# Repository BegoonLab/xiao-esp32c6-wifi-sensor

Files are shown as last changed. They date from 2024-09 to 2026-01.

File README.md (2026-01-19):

# Smart IoT Sensor built with XIAO ESP32C6

**Wi-Fi, MQTT, BME280/BME680/SGP41 Integration & Power Management**

## Table of Contents

- [Introduction](#introduction)
- [Features](#features)
- [Usage](#usage)
- [Schematics](#schematics)
- [Configuration](#configuration)
- [Enclosure](#enclosure)
- [Integration with Home Assistant](#integration-with-home-assistant)
- [Getting Started](#getting-started)
- [Hardware](#hardware)
- [Software](#software)
- [ZigBee](#zigbee)
- [Contributing](#contributing)
- [License](#license)
- [TODO](#todo)

## Introduction

The Smart IoT Sensor is a power-efficient device built using the [XIAO ESP32C6](https://wiki.seeedstudio.com/xiao_esp32c6_getting_started/) tiny board. It integrates Wi-Fi connectivity, MQTT messaging, environmental sensing with BME280/BME680 sensors, and robust power management, making it an ideal solution for smart home and IoT applications.

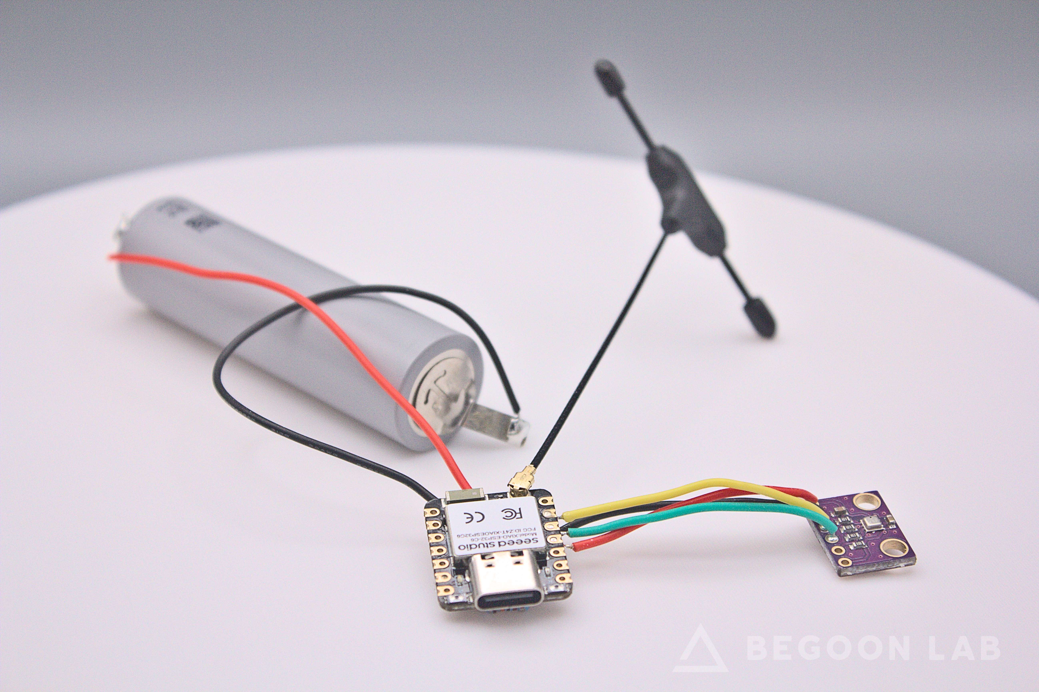
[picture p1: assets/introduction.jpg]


## Features

- **Wi-Fi Connectivity**: Seamless connection to your home or office network.
- **MQTT Integration**: Publishes sensor data to an MQTT broker in JSON format.
- **Environmental Sensing**: Supports [Bosch BME280](https://www.bosch-sensortec.com/products/environmental-sensors/humidity-sensors-bme280/) and [BME680](https://www.bosch-sensortec.com/products/environmental-sensors/gas-sensors/bme680/) sensors for temperature, humidity, and pressure measurements. Supports [Sensirion SGP41](https://sensirion.com/products/catalog/SGP41) VOC and NOx sensor.
- **Power Management**: Efficiently manages power using LiPo batteries with built-in charge management.
- **Deep Sleep Mode**: Extends battery life by enabling deep sleep between data transmissions.
- **ZigBee Connectivity**: Seamless integration with ZigBee networks. Supports standard ZigBee clusters, easily pair your sensor with ZigBee coordinators like Home Assistant.
- **Optional Features**:
  - Battery voltage monitoring
  - Connection duration tracking
  - Future support for Wi-Fi 6 and Bluetooth provisioning (TODO)

## Usage

The Smart IoT Sensor can be easily integrated with [Home Assistant](https://www.home-assistant.io/) for real-time monitoring and automation.

### MQTT Data Structure

The sensor publishes data to an MQTT broker in the following JSON format:

```json
{
  "ID": "7i29r9k9ltaxmbev",
  "RSSI": -54,
  "battery_voltage": 4.13,
  "temperature": "24.28",
  "humidity": "29.32",
  "pressure": "999.54",
  "connection_duration_ms": 1672
}
```

- **ID**: Unique identifier of the sensor
- **RSSI**: Wi-Fi signal strength in dBm
- **battery_voltage**: Current battery voltage
- **temperature**: Temperature reading from the BME sensor
- **humidity**: Humidity reading from the BME sensor
- **pressure**: Pressure reading from the BME sensor
- **connection_duration_ms**: Time taken to establish the MQTT connection

## Schematics

### Battery Connection

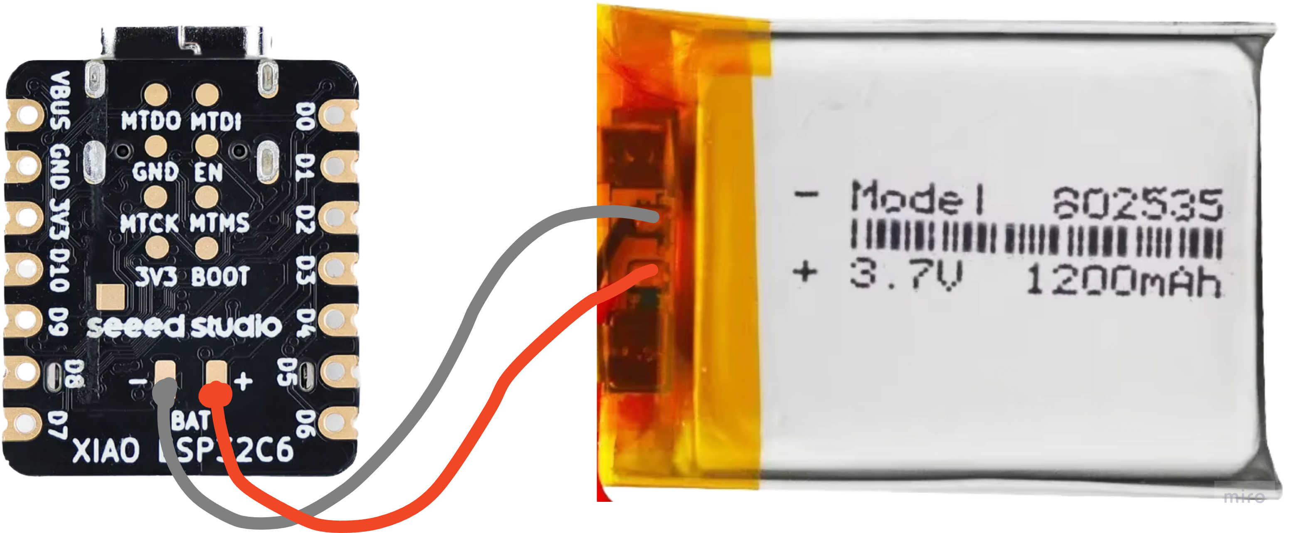
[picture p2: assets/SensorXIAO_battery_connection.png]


_A battery connection schematic._

### Voltage Divider

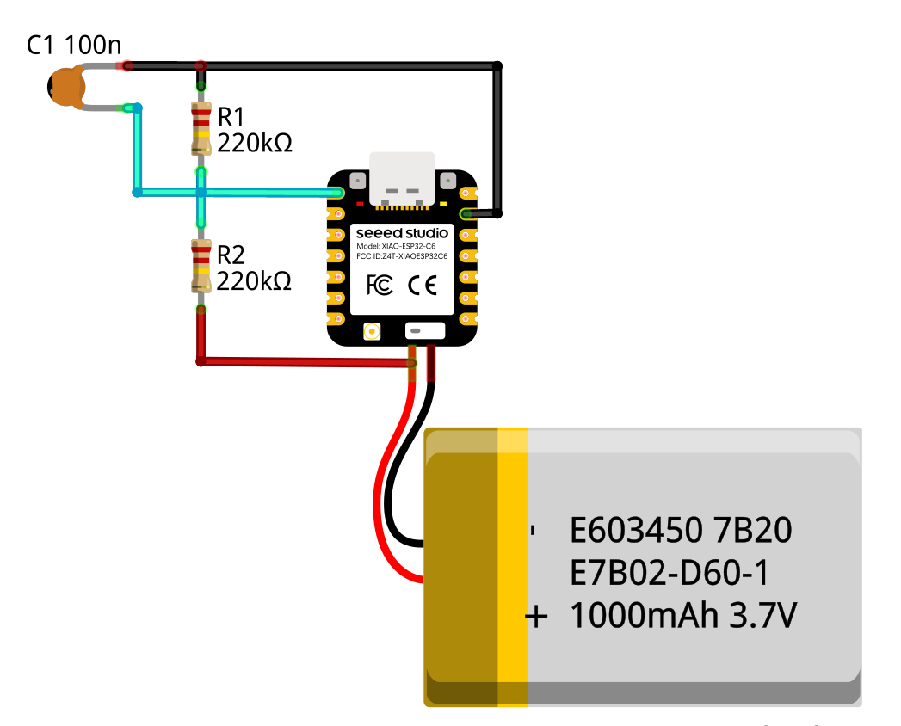
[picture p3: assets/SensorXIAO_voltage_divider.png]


_Voltage divider schematic (if battery voltage monitoring is required)._

**Note:** This solution continuously consumes some current from the battery but is functional for voltage monitoring.

### BME280/BME680 Connection

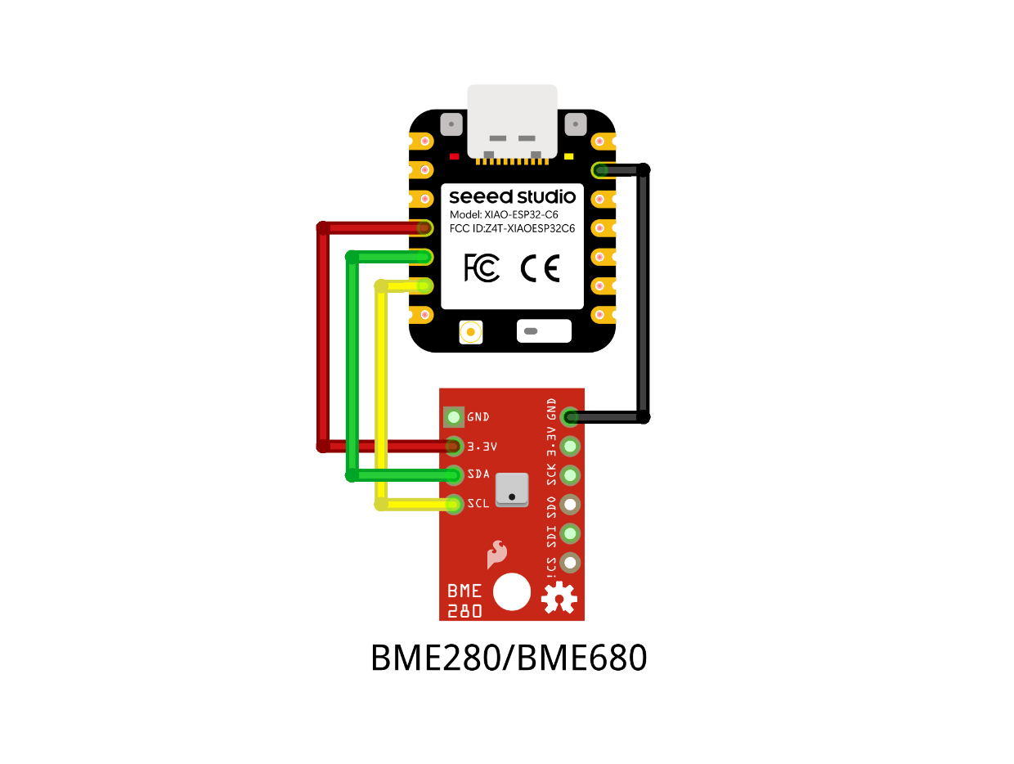
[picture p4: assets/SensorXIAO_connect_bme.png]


### SGP41 Connection

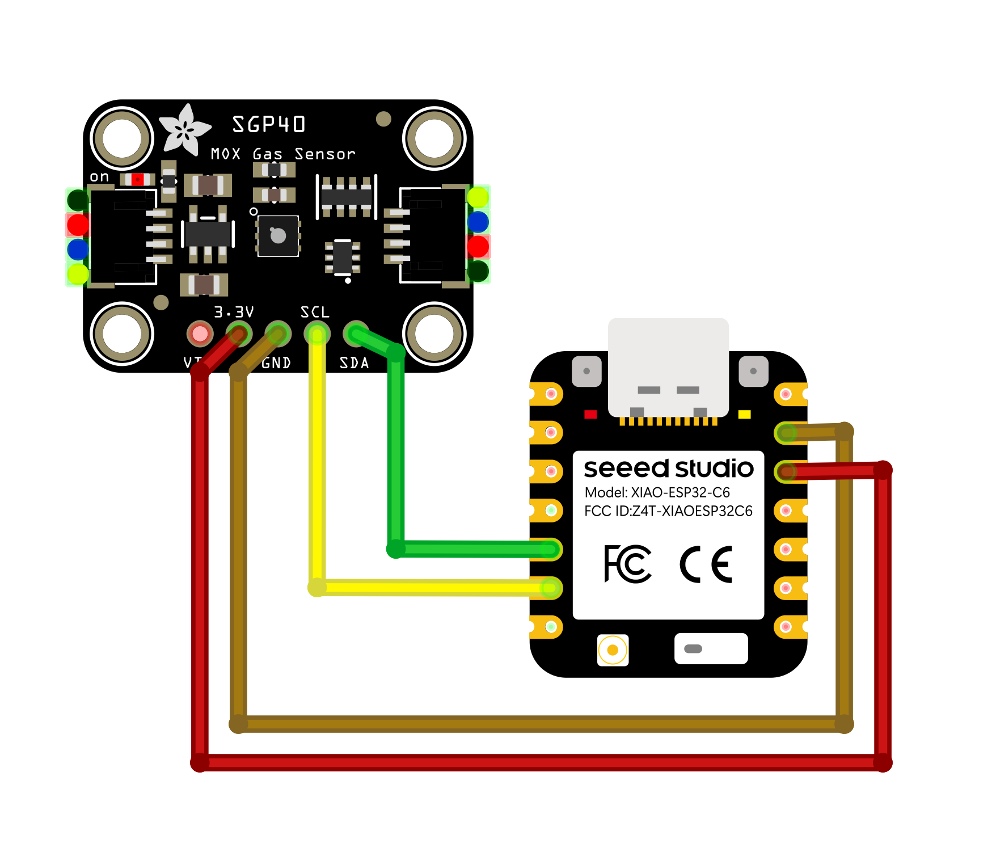
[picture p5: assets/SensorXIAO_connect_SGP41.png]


## Configuration

This build was developed and tested with [ESP-IDF v5.5.2](https://github.com/espressif/esp-idf/releases/tag/v5.5.2)
Follow [this instruction](https://docs.espressif.com/projects/esp-idf/en/v5.5.2/esp32/get-started/index.html#manual-installation) to install it. It is required.

Configure the sensor using the following steps:

```
idf.py menuconfig
```

Then go to `XIAO Sensor Configuration`

1. **Wi-Fi Configuration**: Set up your Wi-Fi credentials to enable network connectivity.
2. **MQTT Configuration**: Connect the sensor to your MQTT server by providing the necessary broker details.
3. **Battery Check (Optional)**: Enable battery voltage monitoring if power management insights are needed.
4. **BME Sensor Configuration (Optional)**: Choose between BME280, BME680 and SGP41 sensors based on your requirements.
5. **Power Management Configuration**: Set up wakeup duration, which is the duration in seconds that the device will remain in deep sleep before waking up.

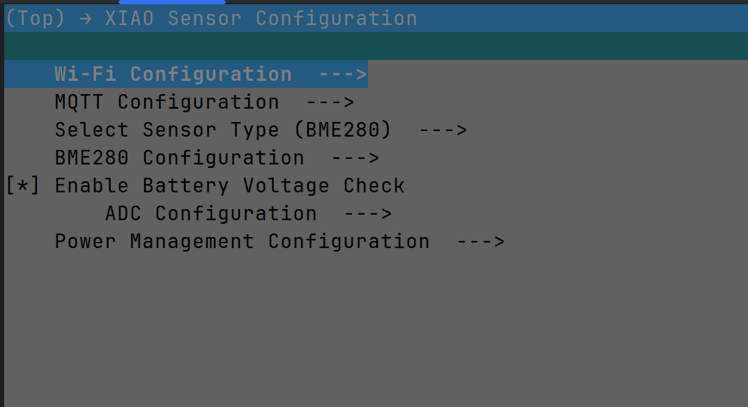
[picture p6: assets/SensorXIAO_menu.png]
6. 

## Enclosure

The sensor is housed in a customizable 3D-printed enclosure. [STL files](3d/enclosure/stl) are available for download and 3D printing.
To customize a model use a [FreeCAD project](3d/enclosure/XIAO_ESP32C6_Enclosure.FCStd).
A 3D preview is available [here](https://begoonlab.tech/cad_design/instructables.com/XIAO_ESP32C6_Enclosure.html).

When printing, it is recommended to orient the parts on the hotbed as shown in the picture:

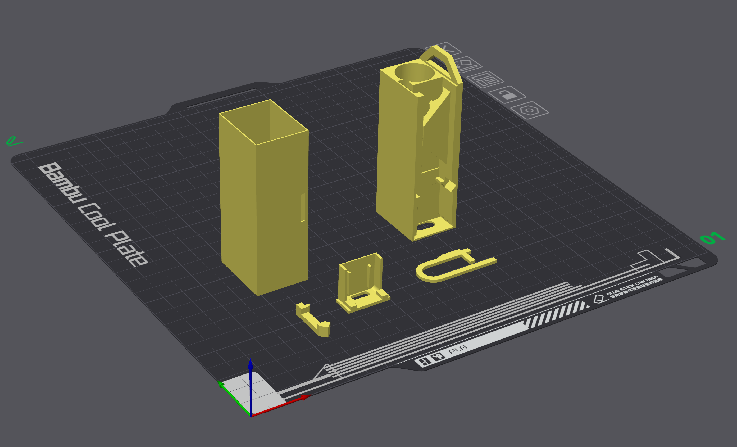
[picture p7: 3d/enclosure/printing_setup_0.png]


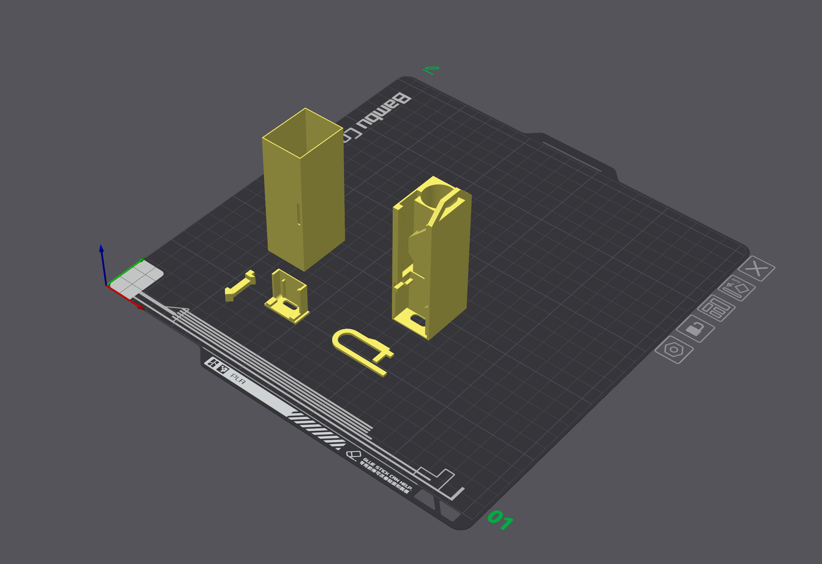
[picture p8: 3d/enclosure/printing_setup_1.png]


Enclosure assembly steps:

1. Insert XIAO board into [SoC_holder](3d/enclosure/stl/soc_holder.stl) :

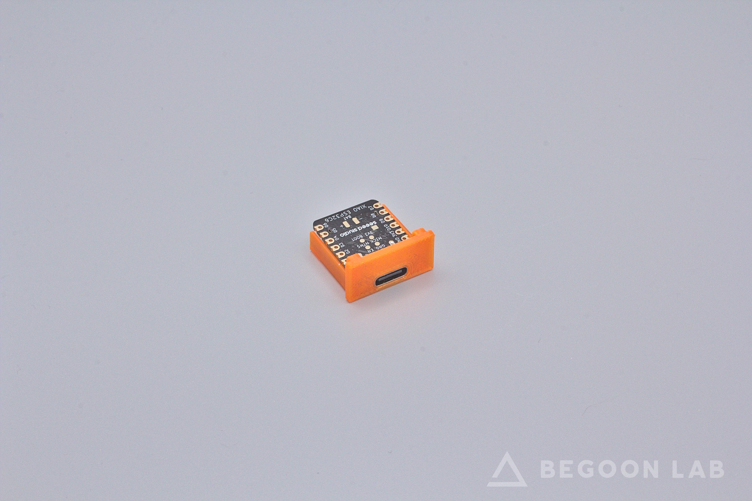
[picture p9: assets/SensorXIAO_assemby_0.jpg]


2. Insert holder into the [core part](3d/enclosure/stl/core.stl) :

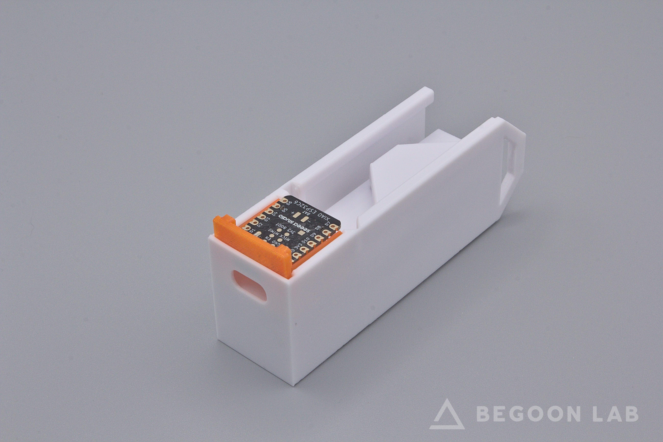
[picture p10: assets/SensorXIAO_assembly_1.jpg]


Pull down until it can't go any farther

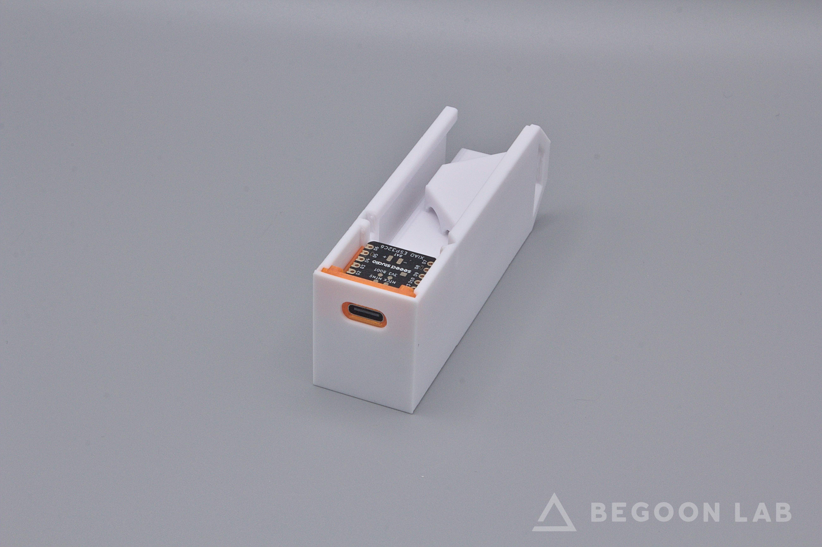
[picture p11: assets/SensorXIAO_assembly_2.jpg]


3. Insert [SoC bracket](3d/enclosure/stl/soc_bracket.stl) :

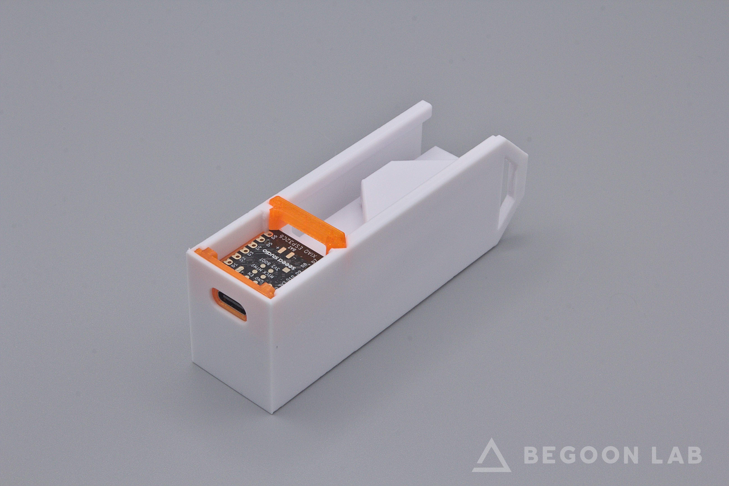
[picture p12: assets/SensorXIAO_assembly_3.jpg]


4. Insert BME sensor

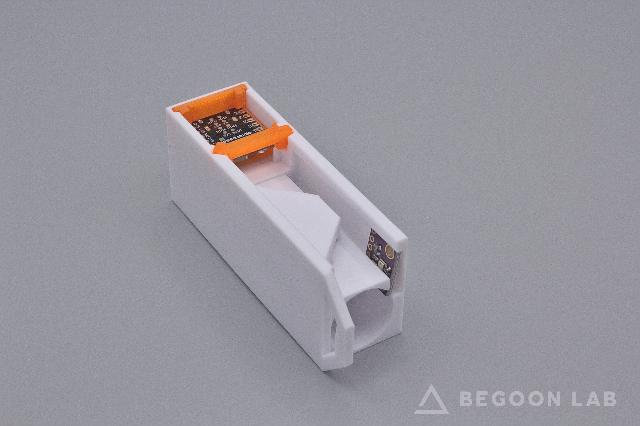
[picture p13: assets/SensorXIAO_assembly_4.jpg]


5. Attach an antenna. Put the coaxial wire into the channels in the core part. Use a couple of drops of glue or double-sided tape to secure the antenna in its place.

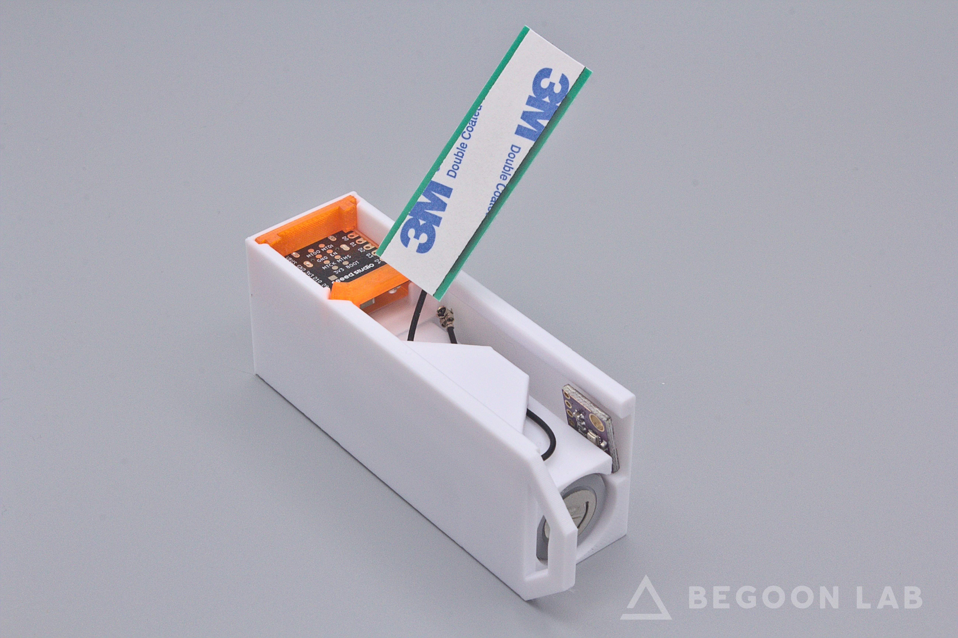
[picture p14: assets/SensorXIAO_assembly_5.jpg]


6. Now solder up everything together according to [schematics](#schematics). And repeat an assembly steps if everything fits nicely.

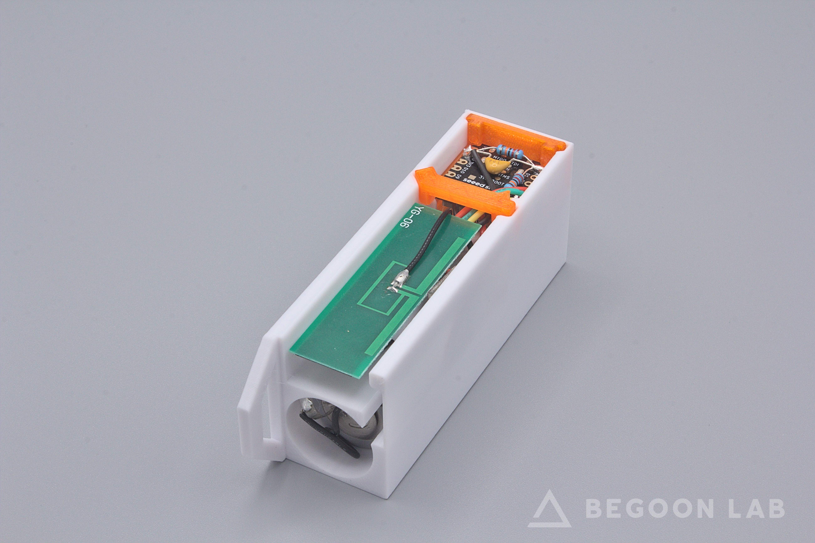
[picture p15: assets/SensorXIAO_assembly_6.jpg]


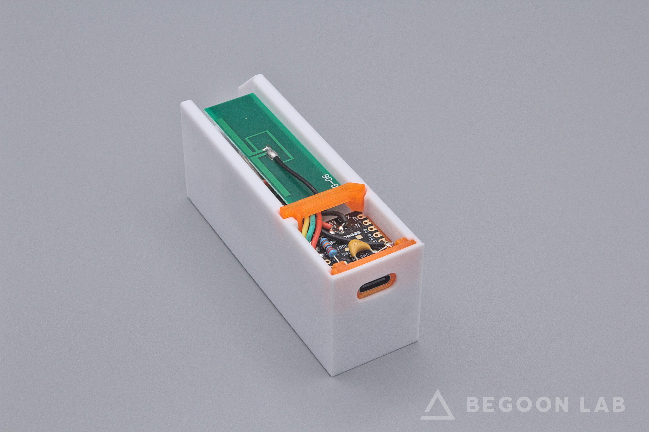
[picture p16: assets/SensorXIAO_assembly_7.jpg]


7. Insert [lock](3d/enclosure/stl/lock.stl) into the [core part](3d/enclosure/stl/core.stl) as shown:

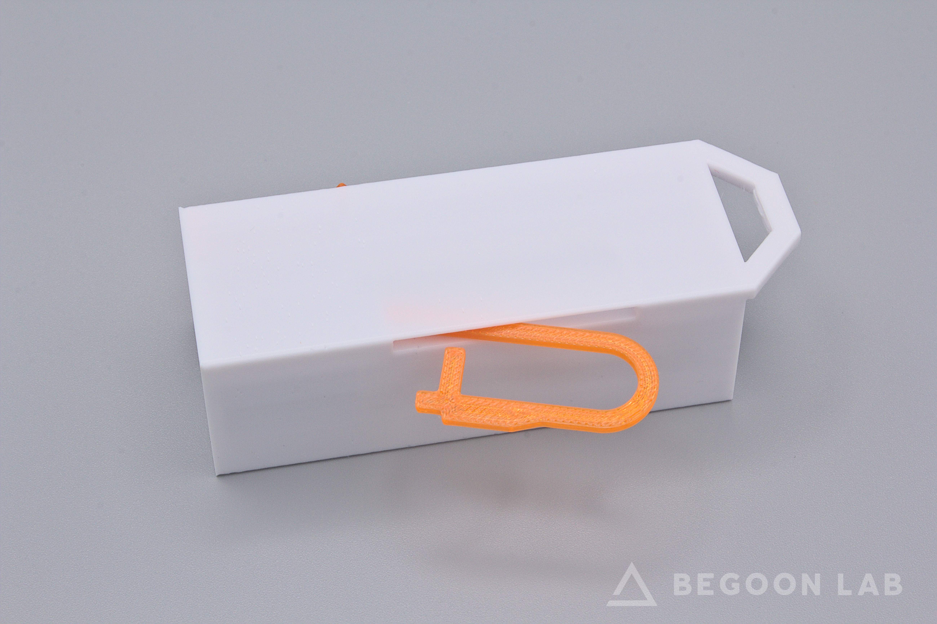
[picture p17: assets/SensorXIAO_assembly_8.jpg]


8. Finally, pull [the wrapper](3d/enclosure/stl/wrapper.stl) onto the [core part](3d/enclosure/stl/core.stl). Ensure that the [lock](3d/enclosure/stl/lock.stl) is securing the wrapper.

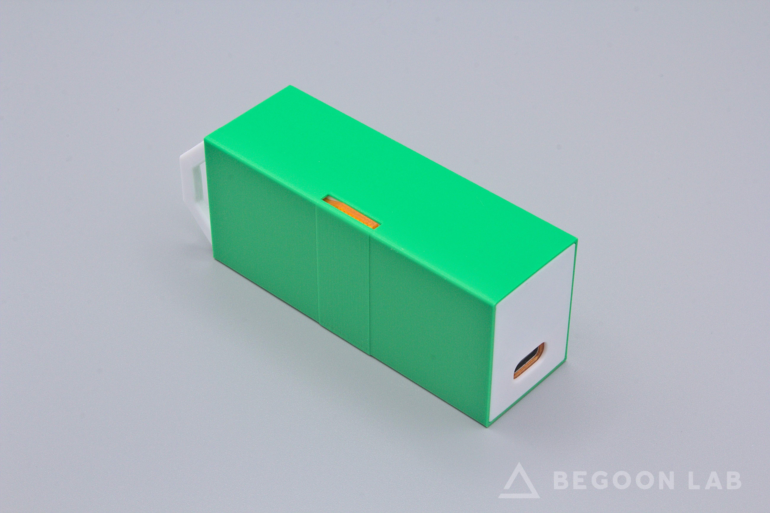
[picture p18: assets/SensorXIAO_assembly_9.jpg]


## Integration with Home Assistant

Integrate the Smart IoT Sensor with Home Assistant by following these steps:

1. **Set Up MQTT Server**: If you don't have an MQTT server, refer to the [Home Assistant MQTT Integration](https://www.home-assistant.io/integrations/mqtt/) guide.
2. **Configure `configuration.yaml`**: Add the following configuration to your `configuration.yaml` file to define the sensor entities.

```yaml
---
mqtt:
  sensor:
    - name: "Sensor RSSI 7i29r9k9ltaxmbev"
      device_class: signal_strength
      state_topic: "xiao/sensor/7i29r9k9ltaxmbev/data"
      unit_of_measurement: "dBm"
      value_template: "{{ value_json.RSSI }}"

    - name: "Sensor Temperature 7i29r9k9ltaxmbev"
      device_class: temperature
      state_topic: "xiao/sensor/7i29r9k9ltaxmbev/data"
      unit_of_measurement: "°C"
      value_template: "{{ value_json.temperature }}"

    - name: "Sensor Humidity 7i29r9k9ltaxmbev"
      device_class: humidity
      state_topic: "xiao/sensor/7i29r9k9ltaxmbev/data"
      unit_of_measurement: "%"
      value_template: "{{ value_json.humidity }}"

    - name: "Sensor Pressure 7i29r9k9ltaxmbev"
      device_class: pressure
      state_topic: "xiao/sensor/7i29r9k9ltaxmbev/data"
      unit_of_measurement: "hPa"
      value_template: "{{ value_json.pressure }}"

    - name: "Sensor Battery Voltage 7i29r9k9ltaxmbev"
      device_class: voltage
      state_topic: "xiao/sensor/7i29r9k9ltaxmbev/data"
      unit_of_measurement: "V"
      value_template: "{{ value_json.battery_voltage }}"

    - name: "Sensor Connection Duration 7i29r9k9ltaxmbev"
      device_class: duration
      state_topic: "xiao/sensor/7i29r9k9ltaxmbev/data"
      unit_of_measurement: "ms"
      value_template: "{{ value_json.connection_duration_ms }}"
```

3. **Restart Home Assistant**: After updating the configuration, restart Home Assistant to apply the changes.
4. **Configure Entity Card**: Here is an example configuration for the entity card:

```yaml
---
type: entities
entities:
  - entity: sensor.sensor_temperature_7i29r9k9ltaxmbev
    icon: mdi:thermometer-low
    secondary_info: last-changed
    name: Temperature
  - entity: sensor.sensor_humidity_7i29r9k9ltaxmbev
    name: Humidity
  - entity: sensor.sensor_pressure_7i29r9k9ltaxmbev
    name: Pressure
  - entity: sensor.sensor_rssi_7i29r9k9ltaxmbev
    icon: mdi:wifi-strength-3
    secondary_info: none
    name: RSSI
  - entity: sensor.sensor_battery_voltage_7i29r9k9ltaxmbev
    icon: mdi:battery-80
    secondary_info: none
    name: Battery
  - entity: sensor.sensor_connection_duration_7i29r9k9ltaxmbev
    name: Connection Duration
title: Sensor 7i29r9k9ltaxmbev
```

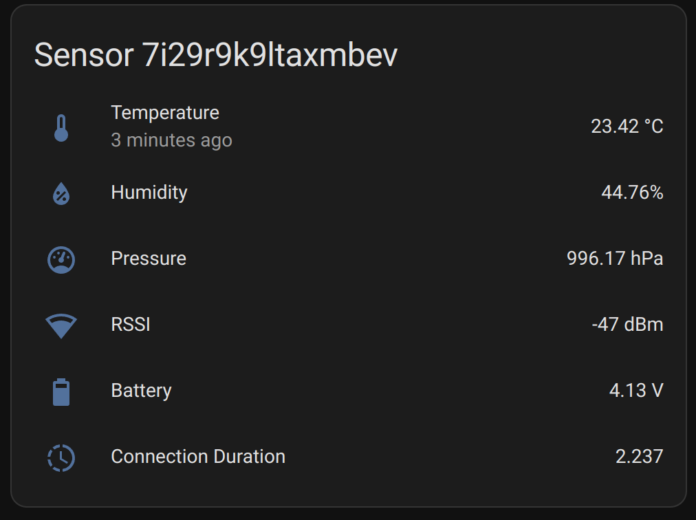
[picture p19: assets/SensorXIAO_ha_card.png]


## Getting Started

Follow these steps to set up your Smart IoT Sensor:

1. **Clone the Repository**

   ```bash
   git clone https://github.com/BegoonLab/xiao-esp32c6-wifi-sensor
   cd xiao-esp32c6-wifi-sensor
   git submodule update --init --recursive
   ```

2. **Install Dependencies**

   Ensure you have the necessary tools and libraries installed. Refer to the [Software](#software) section for more details.

3. **Configure the Sensor**

   Edit the configuration files to set your Wi-Fi and MQTT credentials.

4. **Build and Flash**

   Compile the firmware and flash it to your XIAO ESP32C6 board.

5. **Assemble the Hardware**

   Connect the BME sensor and battery as per the schematics. 3D print the enclosure and assemble the components.

6. **Deploy and Monitor**

   Power on the sensor and monitor the data through your MQTT broker and Home Assistant.

## Hardware

### Components Required

- **XIAO ESP32C6**: The main microcontroller unit.
- **Bosch BME280 or BME680 Sensor**: For measuring temperature, humidity, and pressure.
- **LiPo Battery**: Any standard LiPo battery compatible with XIAO's charge management.
- **Voltage Divider Components**: If battery voltage monitoring is required.
- **Additional Components**:
  - Connectors and cables
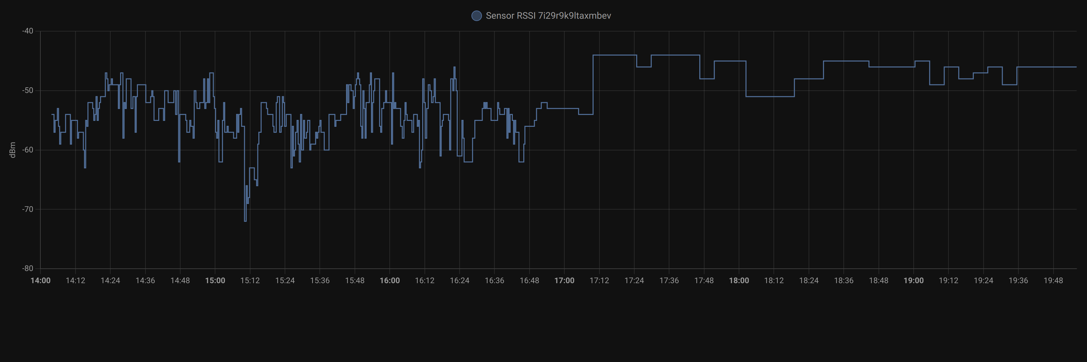
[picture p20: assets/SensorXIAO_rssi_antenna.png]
  - External antenna (optional, but highly recommended for weak Wi-Fi signals). This is RSSI without and then with external antenna: 
    - These antennas tested and worked quite well with this build:
    - PCB Antenna 5dBi and U.FL connector
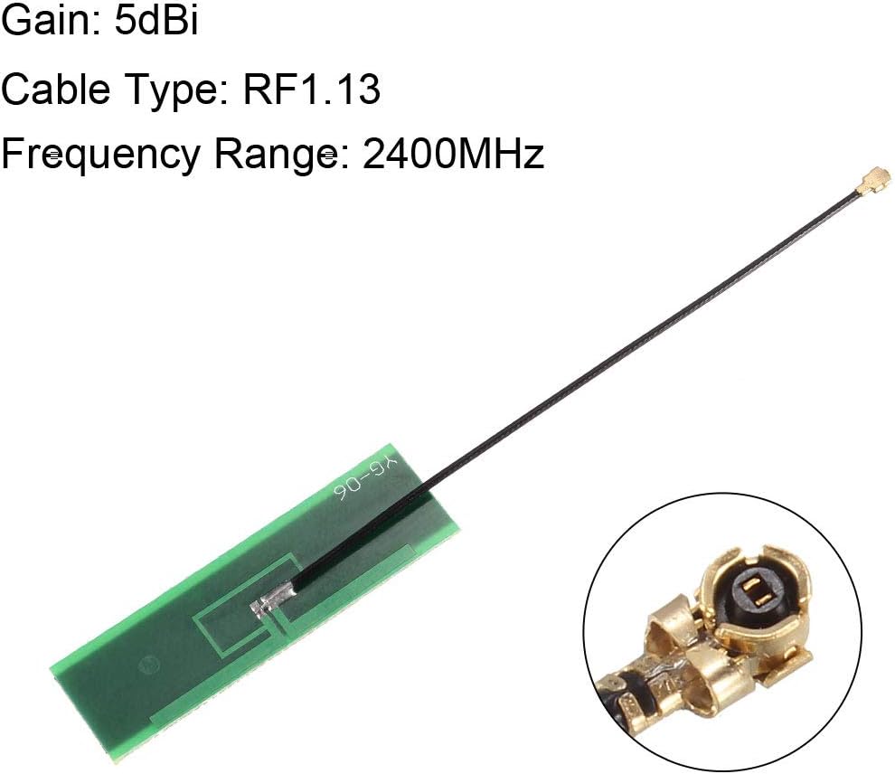
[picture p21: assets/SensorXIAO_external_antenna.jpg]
    - 
    - RadioMaster FPV Drone antenna
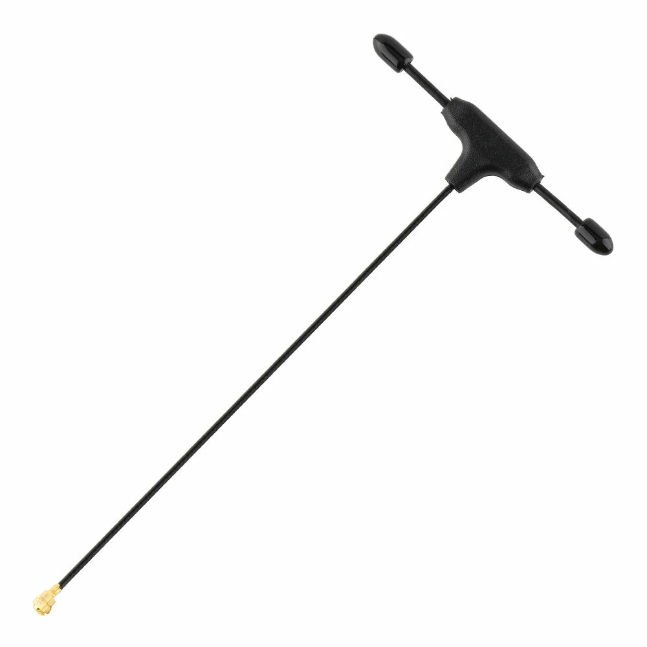
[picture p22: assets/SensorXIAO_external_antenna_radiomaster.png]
    - 

### Assembly Instructions

1. **Mount the Sensor**: Connect the BME280/BME680 to the XIAO ESP32C6.
2. **Connect the Battery**: Ensure the battery is properly connected to the charge management circuitry.
3. **Set Up Voltage Divider**: If monitoring battery voltage, assemble the voltage divider as per the schematic.
4. **Enclose the Assembly**: Use the 3D-printed enclosure to house all components securely.

## Software

### Dependencies

- **ESP-IDF**: [Official development framework](https://docs.espressif.com/projects/esp-idf/en/v5.5.2/esp32/get-started/index.html#software) for Espressif chips.

### Building the Firmware

1. **Install ESP-IDF**

   Follow the [ESP-IDF Getting Started Guide](https://docs.espressif.com/projects/esp-idf/en/v5.5.2/esp32/get-started/index.html) to set up the development environment.

2. **Configure the Project**

   ```bash
   idf.py menuconfig
   ```

   - Set Wi-Fi credentials
   - Configure MQTT broker details
   - Enable or disable optional features

3. **Build and Flash**

   ```bash
   idf.py build
   idf.py -p <TARGET_PORT> flash
   ```

When a sensor misbehaves, it's helpful to output logs to diagnose the issue. By default, logging is disabled. To enable it, follow these steps:

1. Open the configuration menu:
   ```bash
   idf.py menuconfig
   ```
2. Navigate to:
   `Component config` → `Log output` → `Default log verbosity`.
3. Set the verbosity level to `Info`.
4. Save the changes, and then execute the following command to build, flash, and monitor:
   ```bash
   idf.py -p <TARGET_PORT> build flash monitor
   ```

## ZigBee

ZigBee can be activated in the menu:

```bash
idf.py menuconfig
```

Navigate to `XIAO Sensor Configuration` → `Select Sensor Connection Type` → `ZigBee`.

Next, go to `Component config` → `Zigbee` → `Zigbee Enable` and set it to ON. Then, go to `XIAO Sensor Configuration` → `ZigBee Configuration` and set a `Sensor ID`.

Build and flash the firmware. After that, the sensor will be ready and will begin commissioning.

To add the sensor to Home Assistant: go to `Settings` → `Devices & Services` → `Devices` → `Add Device` → `Add Zigbee device`. Once completed, your sensor will appear on the Devices page:

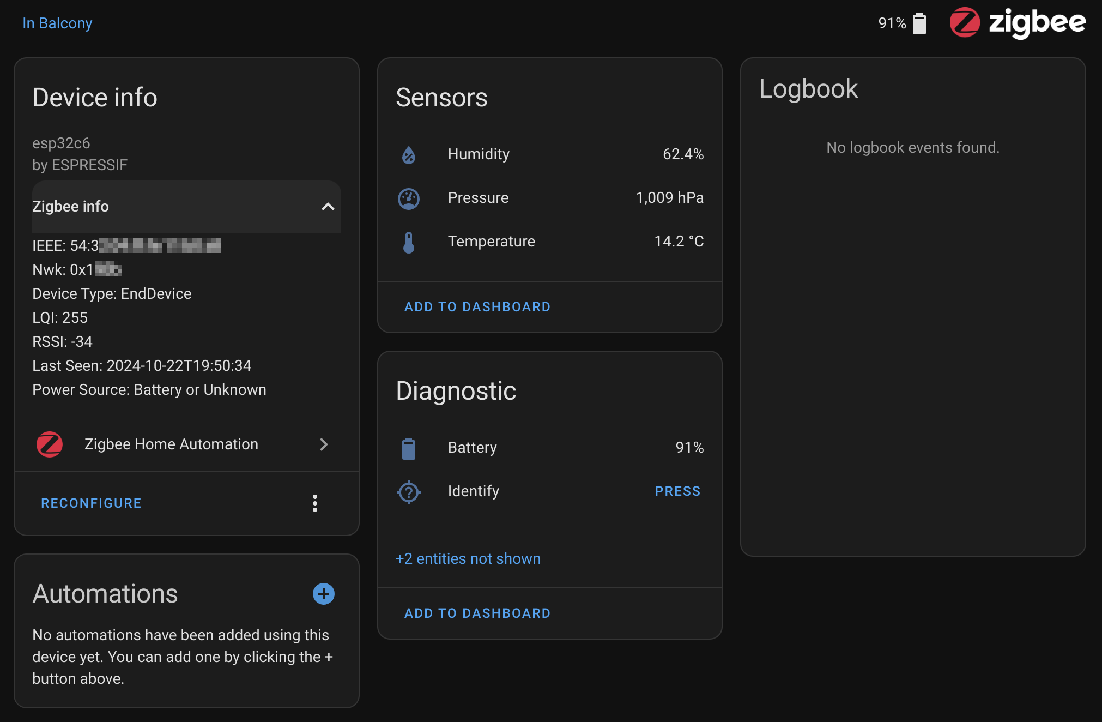
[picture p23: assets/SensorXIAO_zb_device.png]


_Note_: The SGP41 sensor is not currently supported because the ZigBee protocol does not include VOC and NOx clusters in its specification.

## Contributing

Contributions are welcome! Please follow these steps:

1. **Fork the Repository**
2. **Create a Feature Branch**

   ```bash
   git checkout -b feature/YourFeature
   ```

3. **Commit Your Changes**
4. **Push to the Branch**

   ```bash
   git push origin feature/YourFeature
   ```

5. **Open a Pull Request**

## License

This project is licensed under the [MIT License](LICENSE). All rights reserved.

## TODO

- **Wi-Fi 6 Support**: Enhance connectivity options with Wi-Fi 6.
- **Bluetooth Provisioning**: Implement Bluetooth-based provisioning for easier setup.
- **Additional Sensor Support**: Expand compatibility with other types of sensors.

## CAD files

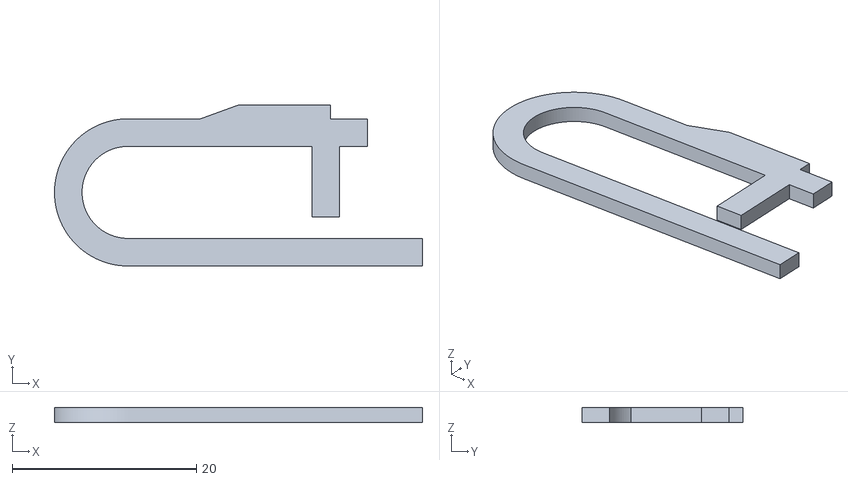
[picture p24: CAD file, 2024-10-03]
3d/enclosure/stl/lock.stl
40.0 x 17.5 x 1.60

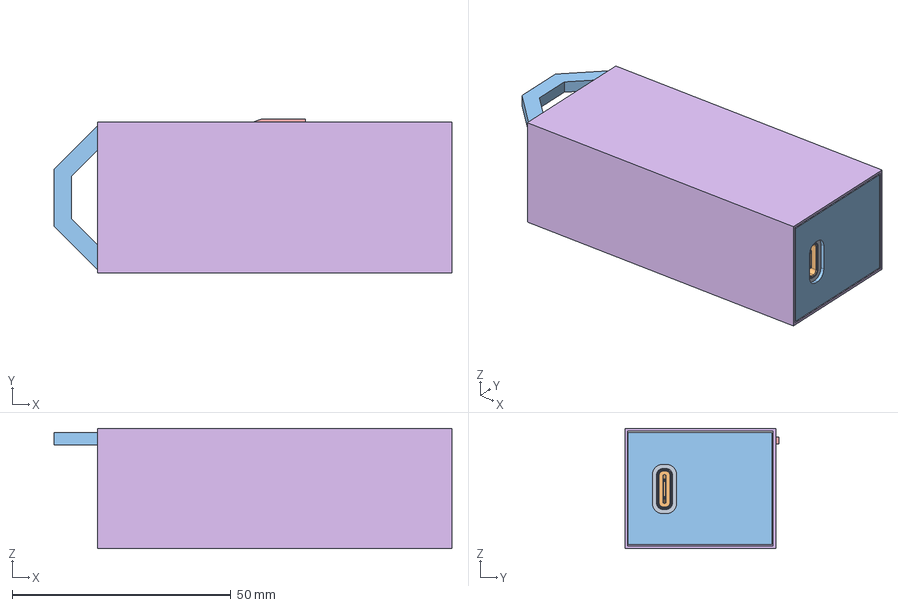
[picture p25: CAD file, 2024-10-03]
3d/enclosure/XIAO_ESP32C6_Enclosure.FCStd
91.0 x 35.2 x 27.5 mm
SoC_holder
Seeed Studio XIAO-ESP32-C3 v016
Core
SoC_bracket
Lock
Wrapper

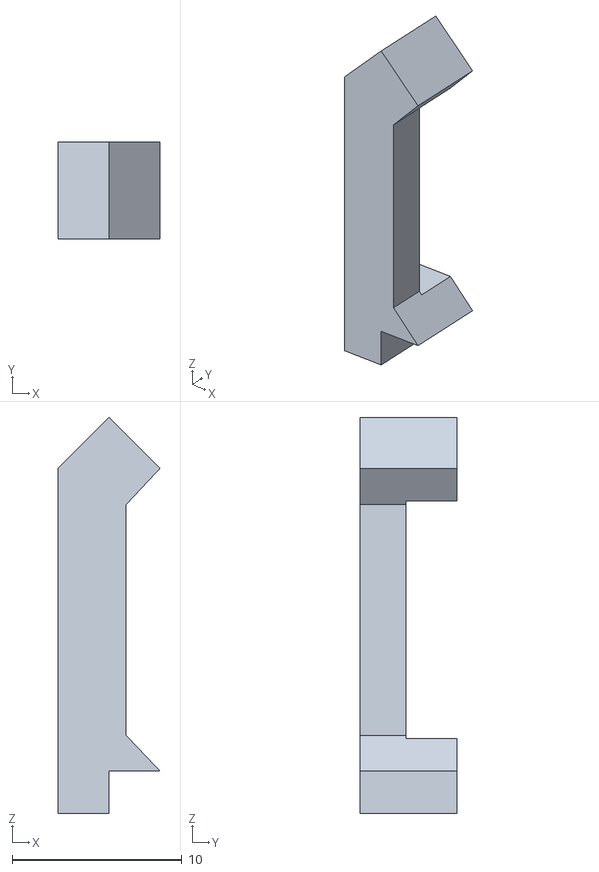
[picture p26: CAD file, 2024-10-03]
3d/enclosure/stl/soc_bracket.stl
6.00 x 5.70 x 23.3

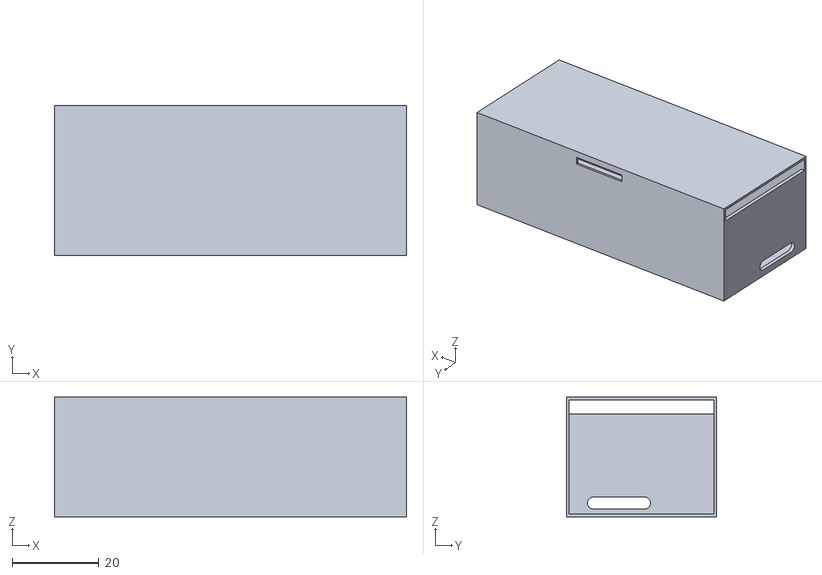
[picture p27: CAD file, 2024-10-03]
3d/enclosure/stl/wrapper.stl
81.0 x 34.5 x 27.5

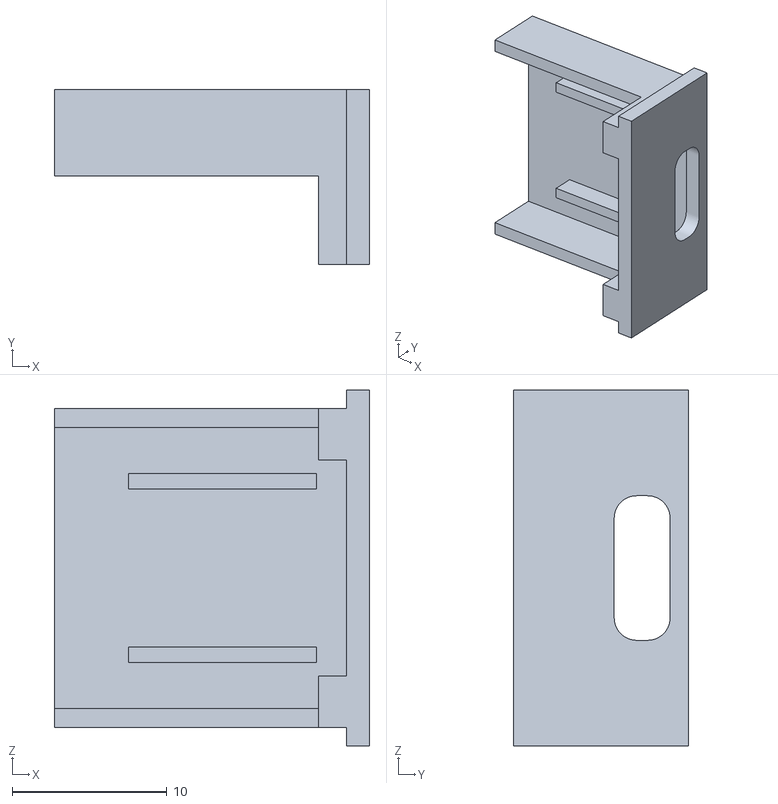
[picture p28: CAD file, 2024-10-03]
3d/enclosure/stl/soc_holder.stl
20.4 x 11.3 x 23.0

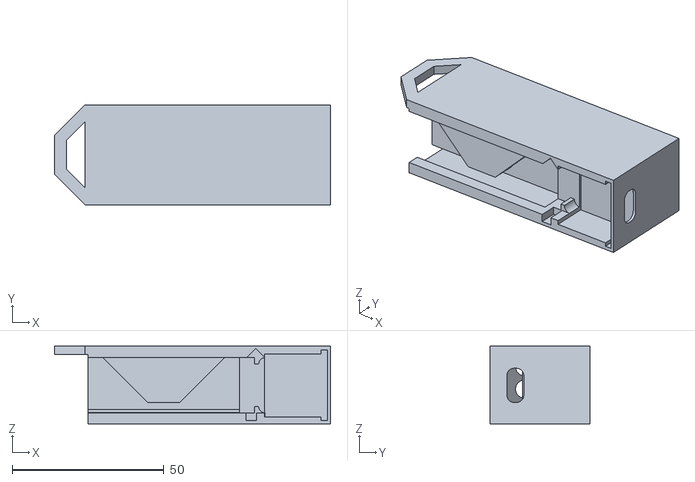
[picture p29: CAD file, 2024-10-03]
3d/enclosure/stl/core.stl
91.0 x 32.8 x 25.7

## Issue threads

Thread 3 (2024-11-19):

Add Sensirion SGP41 support

alexbegoon, 2024-11-19:
Sensor: [https://sensirion.com/de/produkte/katalog/SGP41](https://sensirion.com/de/produkte/katalog/SGP41)
Driver: [https://github.com/Sensirion/embedded-i2c-sgp41](https://github.com/Sensirion/embedded-i2c-sgp41)
Sensirion Gas Index Algorithm: [https://github.com/Sensirion/gas-index-algorithm](https://github.com/Sensirion/gas-index-algorithm)

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

Closed 2024-12-18.

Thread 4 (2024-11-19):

Add BLE support

alexbegoon, 2024-11-19:
Home Assistant private BLE device integration: [](https://www.home-assistant.io/integrations/private_ble_device/)

spanznet, 2025-06-28:
This would be great to work with ESP32 BLE proxy

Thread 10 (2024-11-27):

Built this exactly like instructions

jeffbrown57, 2024-11-27:
using a seeed-studio-esp32c6 and bme280 , configured zigbee built with esp-idf 5.3.1
build successful , flashed it and while monitoring ( using idf.py monitor) its not clear to me if its crashing
i can't add a zigbee device  in homeassistant , and i can't see any topics in MQTT , looking for xiao/

any pointers ???

and thanks for this ....

alexbegoon, 2024-11-28:
Hi @jeffbrown57 ,

The monitor is silent, probably because log output is disabled. To enable it, go to the menu:
```sh
idf.py menuconfig
```

Then navigate to , `Component config` → `Log output` → `Default log verbosity`

and set it to `Info`. Save the configuration, build, and flash again with the monitor using:
```sh
idf.py -p <device/port> build flash monitor.
```

You should now see the output. Feel free to ask for help if needed!

jeffbrown57, 2024-11-28:
thanks so much , i'll let you know

jeffbrown57, 2024-11-30:
Thanks so much for your expert assistance , working great this morning !!

Closed 2024-11-30.

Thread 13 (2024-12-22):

Add Matter-over-Thread support

judahrand, 2024-12-22:
I believe the ESP32C6 should support all of the sensors via Matter over Thread using [ESP-Matter](https://github.com/espressif/esp-matter). This would be incredible as there are pretty much no Matter-over-Thread temperature sensors on the market at the moment.

alexbegoon, 2024-12-23:
Hi @judahrand ,

Yes, that's a great idea. I'll add it in a couple of weeks or so.

alexbegoon, 2025-01-01:
Hi @judahrand  ,
What kind of hub do you use for Matter?

judahrand, 2025-01-01:
> Hi @judahrand , What kind of hub do you use for Matter?

I primarily use a Google Nest Hub but I've also got an OTBR based on an ESP32-S3 with an ESP32-H2 coprocessor knocking around and an Apple Homepod Mini.

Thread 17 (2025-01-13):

Dependencies are incomplete

jeffbrown57, 2025-01-13:
Apologize for my esp-idf ignorance,  i built this with the code available 6 weeks or so ago and all was well. I grabbed a copy of this today and the vendor folder has 3 dependencies that are new, how do get these dependencies added properly. I tried
using  idf.py add-dependency "https://github.com/repo"  for   embedded-i2c-sgp41 , and gas-index-algorithm but i can't
get idf.py menuconfig to work , always complaining abot the missing dependencies.  I thought the
git submodule update --init --recursive. would resolve those .

Thank you for any help you can provide....

alexbegoon, 2025-01-14:
Hi @jeffbrown57 ,

If you're missing `embedded-i2c-sgp41` and `gas-index-algorithm`, try executing `git submodule update`. Also, ensure that you don't have any unstaged changes on your `main` branch.

If the problem persists, please attach the console output as well as the output of `git status`.

jeffbrown57, 2025-01-14:
I reran these steps
git clone https://github.com/BegoonLab/xiao-esp32c6-wifi-sensor
cd xiao-esp32c6-wifi-sensor
git submodule update --init --recursive

all is well now , i think i originally downloaded a zip of the repo ( instead of git clone "https://.......)
cd into it and ran git submodule update ( and it didn;t pull down anything) , after git clone proper
everything worked, my bad !!!

thanks for your help ....

alexbegoon, 2025-01-14:
Hi @jeffbrown57 ,

Anytime! Feel free to reach out if you encounter any issues or have feedback. I truly appreciate it, as it helps me shape this project.

Stay tuned - I’m planning to add [Matter over Thread support](https://github.com/BegoonLab/xiao-esp32c6-wifi-sensor/issues/13) soon!

jeffbrown57, 2025-01-16:
Hi @alexbegoon , this i great news , i have an esp-thread-br  running off of the  espressif thread-border-router kit
anxiously  awaiting this ....

Closed 2025-01-14.

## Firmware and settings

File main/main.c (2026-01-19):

/**
 * @file    main.c
 * @author  Alexander Begoon <alex@begoonlab.tech>
 * @date    27 September 2024
 * @brief   //TODO
 *
 * @details //TODO
 *
 * @copyright Copyright (c) 2024 <a href="https://begoonlab.tech">BegoonLab</a>.
 *            All rights reserved.
 */

#include "sdkconfig.h"
#include "sensor_data.h"
#include "sensor_gpio.h"
#include "sensor_i2c.h"
#include "sensor_id.h"
#include "sensor_led.h"
#include "sensor_nvs.h"
#include "sensor_sleep.h"

#if !defined(GIT_COMMIT_HASH)
#error "GIT_COMMIT_HASH is missing"
#endif

#if defined(CONFIG_SENSOR_BME280) && defined(CONFIG_SENSOR_BME680)
#error                                                                         \
    "Configuration error: Both BME280 and BME680 sensors cannot be connected simultaneously. Please enable only one of these sensors in the configuration."
#endif

#ifdef CONFIG_SENSOR_CONNECTION_WIFI_MQTT
#include "sensor_mqtt.h"
#endif

#ifdef CONFIG_SENSOR_CONNECTION_ZIGBEE
#include "sensor_zb.h"
#endif

#ifdef CONFIG_ENABLE_BATTERY_CHECK
#include "sensor_adc.h"
#endif

#if defined(CONFIG_SENSOR_BME280) || defined(CONFIG_SENSOR_BME680)
#include "sensor_bme.h"
#endif

#ifdef CONFIG_SENSOR_SGP41
#include "sensor_sgp.h"
#endif

static const char *TAG = "sensor_main";

char sensor_id[SENSOR_ID_MAX_LEN] = {0};
SensorData sensor_data;

void app_main(void) {
  init_sensor_data(&sensor_data);
#ifdef CONFIG_ENABLE_BATTERY_CHECK
  init_adc();
  check_battery(&sensor_data);
  ESP_LOGI(TAG, "Battery Voltage: %.2f V", sensor_data.battery.voltage);
  ESP_LOGI(TAG, "FW version: %s", GIT_COMMIT_HASH);
  deinit_adc();
#endif

  init_nvs();
  init_gpio();
  init_led();
  resolve_sensor_id();
  init_i2c();

#ifdef CONFIG_SENSOR_CONNECTION_WIFI_MQTT
  init_mqtt_client();
#endif

#ifdef CONFIG_SENSOR_SGP41
  init_sgp();
  read_sgp();
  deinit_sgp();
#endif

#if defined(CONFIG_SENSOR_BME280) || defined(CONFIG_SENSOR_BME680)
  init_bme();
  read_bme(&sensor_data);
  deinit_bme();
#endif

#ifdef CONFIG_SENSOR_CONNECTION_WIFI_MQTT
  mqtt_send_sensor_data();
  deinit_i2c();
  deinit_sensor_data(&sensor_data);
  go_sleep();
#endif

#ifdef CONFIG_SENSOR_CONNECTION_ZIGBEE
  init_zb();
  start_zb();
#endif
}

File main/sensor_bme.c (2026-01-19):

/**
 * @file    sensor_bme.c
 * @author  Alexander Begoon <alex@begoonlab.tech>
 * @date    30 September 2024
 * @brief   //TODO
 *
 * @details //TODO
 *
 * @copyright Copyright (c) 2024 <a href="https://begoonlab.tech">BegoonLab</a>.
 *            All rights reserved.
 */

#include "sensor_bme.h"

enum { LOW = 0, HIGH = 1 };

#ifdef CONFIG_SENSOR_BME680
static const char *TAG = "sensor_bme680";

static struct bme68x_dev dev;
static struct bme68x_conf conf;
static struct bme68x_heatr_conf heatr_conf;
static struct bme68x_data data;
static uint32_t del_period;
static uint8_t n_fields;
static uint16_t sample_count = 1;

static i2c_master_dev_handle_t bme68x_i2c_handle;
#endif

#ifdef CONFIG_SENSOR_BME280
static const char *TAG = "sensor_bme280";

static uint32_t period;
static struct bme280_dev dev;
static struct bme280_settings settings;

static i2c_master_dev_handle_t bme280_i2c_handle;

static void bme280_init_after_sleep(void) {
  int8_t rslt = bme280_init(&dev);
  bme280_error_codes_print_result("bme280_init", rslt);

  rslt = bme280_get_sensor_settings(&settings, &dev);
  bme280_error_codes_print_result("bme280_get_sensor_settings", rslt);

  /* Configuring the over-sampling rate, filter coefficient and standby time */
  /* Overwrite the desired settings */
  settings.filter = BME280_FILTER_COEFF_2;

  /* Over-sampling rate for humidity, temperature and pressure */
  settings.osr_h = BME280_OVERSAMPLING_1X;
  settings.osr_p = BME280_OVERSAMPLING_1X;
  settings.osr_t = BME280_OVERSAMPLING_1X;

  /* Setting the standby time */
  settings.standby_time = BME280_STANDBY_TIME_0_5_MS;

  rslt = bme280_set_sensor_settings(BME280_SEL_ALL_SETTINGS, &settings, &dev);
  bme280_error_codes_print_result("bme280_set_sensor_settings", rslt);
}
#endif

void init_bme(void) {

#ifdef CONFIG_SENSOR_BME680
  esp_rom_gpio_pad_select_gpio(CONFIG_BME680_POWER_PIN);
  gpio_reset_pin(CONFIG_BME680_POWER_PIN);
  gpio_set_direction(CONFIG_BME680_POWER_PIN, GPIO_MODE_OUTPUT);

  gpio_set_level(CONFIG_BME680_POWER_PIN, HIGH);
  ESP_LOGI(TAG, "BME680 powered on");

  vTaskDelay(pdMS_TO_TICKS(25));

  bme68x_i2c_handle = get_i2c_device(CONFIG_BME680_I2C_ADDR);

  dev.read = bme68x_i2c_read;
  dev.write = bme68x_i2c_write;
  dev.delay_us = bme68x_delay_us;
  dev.intf = BME68X_I2C_INTF;

  int8_t rslt = bme68x_init(&dev);
  bme68x_error_codes_print_result("bme68x_init", rslt);

  conf.filter = BME68X_FILTER_OFF;
  conf.odr = BME68X_ODR_NONE;
  conf.os_hum = BME68X_OS_16X;
  conf.os_pres = BME68X_OS_1X;
  conf.os_temp = BME68X_OS_2X;
  rslt = bme68x_set_conf(&conf, &dev);
  bme68x_error_codes_print_result("bme68x_set_conf", rslt);

  heatr_conf.enable = BME68X_ENABLE;
  heatr_conf.heatr_temp = 300;
  heatr_conf.heatr_dur = 100;
  rslt = bme68x_set_heatr_conf(BME68X_FORCED_MODE, &heatr_conf, &dev);
  bme68x_error_codes_print_result("bme68x_set_heatr_conf", rslt);
#endif

#ifdef CONFIG_SENSOR_BME280
  esp_rom_gpio_pad_select_gpio(CONFIG_BME280_POWER_PIN);
  gpio_reset_pin(CONFIG_BME280_POWER_PIN);
  gpio_set_direction(CONFIG_BME280_POWER_PIN, GPIO_MODE_OUTPUT);

  gpio_set_level(CONFIG_BME280_POWER_PIN, HIGH);
  vTaskDelay(pdMS_TO_TICKS(100));
  gpio_set_level(CONFIG_BME280_POWER_PIN, LOW);
  vTaskDelay(pdMS_TO_TICKS(100));
  gpio_set_level(CONFIG_BME280_POWER_PIN, HIGH);
  ESP_LOGI(TAG, "BME280 powered on");

  vTaskDelay(pdMS_TO_TICKS(25));

  bme280_i2c_handle = get_i2c_device(CONFIG_BME280_I2C_ADDR);

  dev.read = bme280_i2c_read;
  dev.write = bme280_i2c_write;
  dev.delay_us = bme280_delay_us;
  dev.intf = BME280_I2C_INTF;

  int8_t rslt = 0;
  bme280_init_after_sleep();

  /* Always set the power mode after setting the configuration */
  rslt = bme280_set_sensor_mode(BME280_POWERMODE_NORMAL, &dev);
  bme280_error_codes_print_result("bme280_set_power_mode", rslt);

  /* Calculate measurement time in microseconds */
  rslt = bme280_cal_meas_delay(&period, &settings);
  bme280_error_codes_print_result("bme280_cal_meas_delay", rslt);

  ESP_LOGI(TAG, "Measurement time : %lu us", (long unsigned int)period);
#endif
}

void read_bme(SensorData *sensor_data) {
  if (xSemaphoreTake(sensor_data->mutex, portMAX_DELAY) == pdTRUE) {
#ifdef CONFIG_SENSOR_BME680
    int8_t rslt = 0;
    while (sample_count <= SAMPLE_COUNT) {
      rslt = bme68x_set_op_mode(BME68X_FORCED_MODE, &dev);
      bme68x_error_codes_print_result("bme68x_set_op_mode", rslt);

      /* Calculate delay period in microseconds */
      del_period = bme68x_get_meas_dur(BME68X_FORCED_MODE, &conf, &dev) +
                   (heatr_conf.heatr_dur * 1000);
      dev.delay_us(del_period, dev.intf_ptr);

      /* Check if rslt == BME68X_OK, report or handle if otherwise */
      rslt = bme68x_get_data(BME68X_FORCED_MODE, &data, &n_fields, &dev);
      bme68x_error_codes_print_result("bme68x_get_data", rslt);

      if (n_fields) {
        sensor_data->temperature = data.temperature;
        sensor_data->pressure = data.pressure;
        sensor_data->humidity = data.humidity;
        sample_count++;
      }
    }
#endif

#ifdef CONFIG_SENSOR_BME280
    bme280_init_after_sleep();

    int8_t rslt = bme280_set_sensor_mode(BME280_POWERMODE_NORMAL, &dev);
    bme280_error_codes_print_result("bme280_set_sensor_mode", rslt);

    rslt = bme280_get_temperature(&sensor_data->temperature);
    bme280_error_codes_print_result("bme280_get_temperature", rslt);

    rslt = bme280_get_humidity(&sensor_data->humidity);
    bme280_error_codes_print_result("bme280_get_humidity", rslt);

    rslt = bme280_get_pressure(&sensor_data->pressure);
    bme280_error_codes_print_result("bme280_get_pressure", rslt);

    bme280_set_sensor_mode(BME280_POWERMODE_SLEEP, &dev);
    bme280_error_codes_print_result("bme280_set_sensor_mode", rslt);
#endif

#if defined(CONFIG_SENSOR_BME280) || defined(CONFIG_SENSOR_BME680)
    convert_values(&sensor_data->temperature, &sensor_data->humidity,
                   &sensor_data->pressure);
#endif
    xSemaphoreGive(sensor_data->mutex);
  }
}

void deinit_bme(void) {
#ifdef CONFIG_SENSOR_BME680
  release_i2c_device(bme68x_i2c_handle);
  gpio_set_level(CONFIG_BME680_POWER_PIN, LOW);
#endif

#ifdef CONFIG_SENSOR_BME280
  release_i2c_device(bme280_i2c_handle);
  gpio_set_level(CONFIG_BME280_POWER_PIN, LOW);
#endif
}

void convert_values(double *temperature, double *humidity, double *pressure) {
  // Round temperature and humidity to two decimal places
  *temperature = round(*temperature * 100.0) / 100.0;
  *humidity = round(*humidity * 100.0) / 100.0;

  // Convert pressure from Pa to hPa and round to two decimal places
  *pressure = round((*pressure / 100.0) * 100.0) / 100.0;
}

#ifdef CONFIG_SENSOR_BME280
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

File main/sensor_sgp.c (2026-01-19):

/**
 * @file    sensor_sgp.c
 * @author  Alexander Begoon <alex@begoonlab.tech>
 * @date    20 November 2024
 * @brief   //TODO
 *
 * @details //TODO
 *
 * @copyright Copyright (c) 2024 <a href="https://begoonlab.tech">BegoonLab</a>.
 *            All rights reserved.
 */

#include "sensor_sgp.h"

#ifdef CONFIG_SENSOR_SGP41

static const char *TAG = "sensor_sgp41";

extern SensorData sensor_data;

GasIndexAlgorithmParams voc_params;
GasIndexAlgorithmParams nox_params;

uint16_t DEFAULT_COMPENSATION_RH = 0x8000; // in ticks as defined by SGP41
uint16_t DEFAULT_COMPENSATION_T = 0x6666;  // in ticks as defined by SGP41

TaskHandle_t send_data_task_handle = NULL;

static i2c_master_dev_handle_t sgp41_i2c_handle;

const float sampling_interval = 10.F;
int32_t send_data_after = CONFIG_WAKEUP_TIME_SEC + 60;
volatile bool can_go_sleep = true;

void init_sgp(void) {
  GasIndexAlgorithm_init_with_sampling_interval(
      &voc_params, GasIndexAlgorithm_ALGORITHM_TYPE_VOC, sampling_interval);
  GasIndexAlgorithm_init_with_sampling_interval(
      &nox_params, GasIndexAlgorithm_ALGORITHM_TYPE_NOX, sampling_interval);

  sensirion_i2c_hal_init();

#if defined(CONFIG_SENSOR_BME280) || defined(CONFIG_SENSOR_BME680)
  init_bme();
#endif

  xTaskCreate(send_data_task, "Send_Data_Task", 8192, NULL, 5,
              &send_data_task_handle);
}

void read_sgp() {

  int16_t error = 0;
  uint16_t serial_number[3];
  uint16_t compensation_rh = DEFAULT_COMPENSATION_RH;
  uint16_t compensation_t = DEFAULT_COMPENSATION_T;

  error = sgp41_get_serial_number(serial_number);
  if (error) {
    ESP_LOGE(TAG, "Error executing sgp41_get_serial_number(): %i", error);
  } else {
    ESP_LOGI(TAG, "serial: 0x%04x%04x%04x", serial_number[0], serial_number[1],
             serial_number[2]);
  }

  uint16_t test_result = 0;

  error = sgp41_execute_self_test(&test_result);
  if (error) {
    ESP_LOGE(TAG, "Error executing sgp41_execute_self_test(): %i", error);
  } else {
    ESP_LOGI(TAG, "Self Test: 0x%x", test_result);
  }

  uint16_t nox_conditioning_s = 8;

  while (nox_conditioning_s > 0) {
    sensirion_i2c_hal_sleep_usec(1000000);

    error = sgp41_execute_conditioning(
        DEFAULT_COMPENSATION_RH, DEFAULT_COMPENSATION_T, &sensor_data.sraw_voc);
    nox_conditioning_s--;
    ESP_LOGI(TAG, "NOx conditioning remaining time: %i s", nox_conditioning_s);

    if (error) {
      ESP_LOGE(TAG, "Error executing sgp41_execute_conditioning(): %i", error);
    }
  }

  while (1) {
    send_data_after -= (int32_t)sampling_interval;

    if (send_data_after < 0 && can_go_sleep == true) {
      can_go_sleep = false;
      xTaskNotify(send_data_task_handle, 1, eSetValueWithoutOverwrite);
    }

    sensirion_i2c_hal_sleep_usec(((uint32_t)(sampling_interval * 1000) - 240) *
                                 1000);

    // Measure RH and T signals and convert to SGP40 ticks
    read_compensation_values(&compensation_rh, &compensation_t);

    // Request a first measurement to turn the heater on
    if (xSemaphoreTake(sensor_data.mutex, portMAX_DELAY) == pdTRUE) {
      error = sgp41_measure_raw_signals(compensation_rh, compensation_t,
                                        &sensor_data.sraw_voc,
                                        &sensor_data.sraw_nox);
      xSemaphoreGive(sensor_data.mutex);
    }

    if (error) {
      ESP_LOGE(TAG, "Error executing sgp41_measure_raw_signals(): %i", error);
      continue;
    }

    // Wait for the heater to reach temperature
    sensirion_i2c_hal_sleep_usec(170000);

    // Request the actual measurement
    if (xSemaphoreTake(sensor_data.mutex, portMAX_DELAY) == pdTRUE) {
      error = sgp41_measure_raw_signals(compensation_rh, compensation_t,
                                        &sensor_data.sraw_voc,
                                        &sensor_data.sraw_nox);
      xSemaphoreGive(sensor_data.mutex);
    }

    if (error) {
      ESP_LOGE(TAG, "Error executing sgp41_measure_raw_signals(): %i", error);
      continue;
    }

    // Turn the heater off
    error = sgp41_turn_heater_off();

    if (error) {
      ESP_LOGE(TAG, "Error executing sgp41_turn_heater_off(): %i", error);
      continue;
    }

    // Process raw signals by Gas Index Algorithm
    // to get the VOC and NOx index values
    if (xSemaphoreTake(sensor_data.mutex, portMAX_DELAY) == pdTRUE) {
      GasIndexAlgorithm_process(&voc_params, sensor_data.sraw_voc,
                                &sensor_data.voc_index_value);
      GasIndexAlgorithm_process(&nox_params, sensor_data.sraw_nox,
                                &sensor_data.nox_index_value);
      ESP_LOGI(TAG, "VOC Raw: %i\tVOC Index: %li\tNOx Raw: %i\tNOx Index: %li",
               sensor_data.sraw_voc, sensor_data.voc_index_value,
               sensor_data.sraw_nox, sensor_data.nox_index_value);
      xSemaphoreGive(sensor_data.mutex);
    }
  }
}

void deinit_sgp(void) {
#if defined(CONFIG_SENSOR_BME280) || defined(CONFIG_SENSOR_BME680)
  deinit_bme();
#endif
  sensirion_i2c_hal_free();
}

void sensirion_i2c_hal_init(void) {
  sgp41_i2c_handle = get_i2c_device(CONFIG_SGP41_I2C_ADDR);
}

void sensirion_i2c_hal_free(void) { release_i2c_device(sgp41_i2c_handle); }

int8_t sensirion_i2c_hal_read(uint8_t address __attribute__((unused)),
                              uint8_t *data, uint16_t count) {
  esp_err_t err = ESP_FAIL;
  static uint8_t attempt = 0;
  do {
    err = i2c_master_receive(sgp41_i2c_handle, data, count, -1);
    attempt++;
  } while (err != ESP_OK && attempt < 5);

  ESP_ERROR_CHECK(err);

  return (int8_t)err;
}

int8_t sensirion_i2c_hal_write(uint8_t address __attribute__((unused)),
                               const uint8_t *data, uint16_t count) {
  esp_err_t err = ESP_FAIL;
  static uint8_t attempt = 0;

  do {
    err = i2c_master_transmit(sgp41_i2c_handle, data, count, -1);
    attempt++;
  } while (err != ESP_OK && attempt < 5);

  ESP_ERROR_CHECK(err);

  return (int8_t)err;
}

void sensirion_i2c_hal_sleep_usec(uint32_t useconds) {
  if (can_go_sleep && useconds > 100000) {
    sensirion_i2c_hal_free();
    esp_sleep_enable_timer_wakeup(useconds);
    esp_light_sleep_start();
    sensirion_i2c_hal_init();
  } else {
    uint32_t msec = useconds / 1000;
    msec += 10;
    vTaskDelay(pdMS_TO_TICKS(msec));
  }
}

// Task to handle data sending
void send_data_task(void *pvParameters __attribute__((unused))) {
  uint32_t notification = 0;
  while (1) {
    // Wait indefinitely for a notification to send data
    if (xTaskNotifyWait(0, ULONG_MAX, &notification,
                        pdMS_TO_TICKS(CONFIG_WAKEUP_TIME_SEC * 1000)) ==
        pdTRUE) {
      if (notification == 1) { // Command to send data
#ifdef CONFIG_ENABLE_BATTERY_CHECK
        init_adc();
        check_battery(&sensor_data);
        deinit_adc();
#endif
        mqtt_send_sensor_data();
        can_go_sleep = true;
        send_data_after = CONFIG_WAKEUP_TIME_SEC;
      }
    }
  }
}
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

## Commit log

2024-09-28 WIP
    Add configuration
    Add WIFI connection
    Add MQTT client
    Add support of external antenna
2024-09-29 WIP
    Add battery voltage check
2024-09-30 WIP
    Add BME sensors support
2024-09-30 WIP
    Add README.md
    [SensorXIAO.fzz]
2024-10-01 Improve README.md
    [SensorXIAO.fzz]
2024-10-03 Add enclosure CAD files and project
    [XIAO_ESP32C6_Enclosure.FCStd, core.stl, lock.stl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]
2024-10-03 Add assembly instruction
2024-10-25 Add LED status Improve gitignore Refactor WiFi part Add partitions scheme Add default config Add ZigBee menu Add ZigBee support
    [partitions.csv]
2024-11-20 Add trunk code linter
    [.isort.cfg]
2024-11-20 Add Sensor ID fallback
2024-12-18 Add SGP41 support remove esp-idf-lib Setup CMake
    [SensorXIAO.fzz]
2024-12-28 Fix missing battery check
    [main.c, sensor_adc.c, sensor_bme.c]
